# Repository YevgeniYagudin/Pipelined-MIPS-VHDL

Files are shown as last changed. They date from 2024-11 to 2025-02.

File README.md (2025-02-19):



Pipelined MIPS Processor
This project implements a pipelined MIPS processor written in VHDL, designed for integration on an Altera FPGA. The architecture efficiently executes instructions with support for stalls and flushes to handle hazards and maintain correct program behavior.
The design follows a five-stage pipeline, with each stage handled by a distinct sub-entity:

1. Ifetch (Instruction Fetch):
Reads program instructions and data from memory.
Passes the instruction to the next pipeline stage.

2. Idecode (Instruction Decode):
Decodes the instruction fetched by Ifetch.
Reads/writes data to/from registers as required by the instruction.

3. Execute:
Performs mathematical or logical operations on data from Idecode registers.
Outputs results for memory access or writes back to registers.

4. Dmemory (Data Memory):
Handles load and store operations.
Manages memory access as specified by the instruction.

5. Write Back:
Stores the result of execute stage in memory.

Control:
Enables or disables control signals for all components based on the current instruction.
Ensures correct operation and hazard handling.

Features
Pipelined Execution: Five-stage pipeline ensures efficient instruction throughput.
Hazard Handling: Supports stalls and flushes for resolving data and control hazards.
Supported Instructions: Implements the instructions specified by assignment requirements.
FPGA Integration: Designed for synthesis and deployment on FPGA hardware.
Deliverables
RTL Code: Fully implemented in VHDL.
Documentation: Includes design overview, block diagrams, and operational details.
Tested and verified on Quartus, ModelSim and QuestaSim. Integrated on Altera FPGA.

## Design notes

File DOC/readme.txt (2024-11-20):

The design includes a pipelined MIPS architecture.

Supported instructions are according to the assignment requirements.

The architecture supports stalls and flushes.

The top entity includes 5 main sub entities:

1.	Ifetch: Reads the program data, the instruction, and passes it to the next element.

2.	Idecode: Gets the instruction from Ifetch and reads/writes to registers.

3.	Control: Gets the instruction from Ifetch and enables/disables control signals to all relevant components.

4.	Execute: Gets the instruction from Idecode and applies mathematical operations on data given by Idecode registers.

5.	Dmemory: Loads and stores data according to instruction.

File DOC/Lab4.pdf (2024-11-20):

# CPU Architecture

# LAB 4 assignment

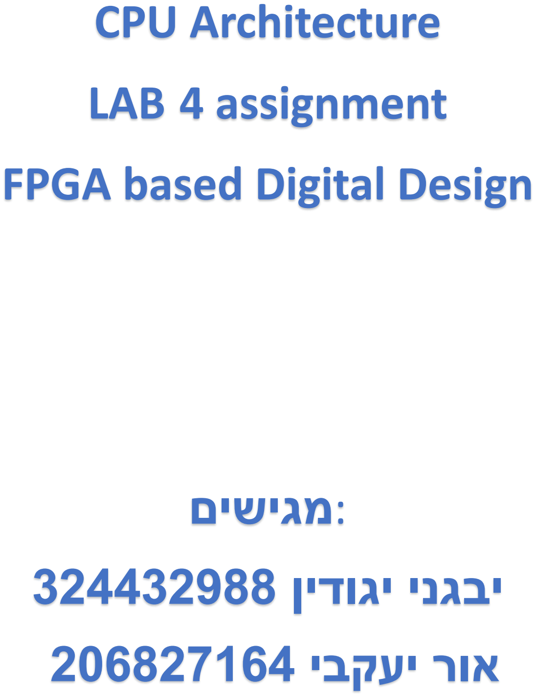
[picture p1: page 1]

# FPGA based Digital Design

# :מגישים

# יבגני יגודין 324432988

# אור יעקבי 206827164

חישוב התדר המקסימלי:

נעטוף ברגיסטרים את ה-ALU שלנו )TOP )כפי שהתבקש באיור הבא:

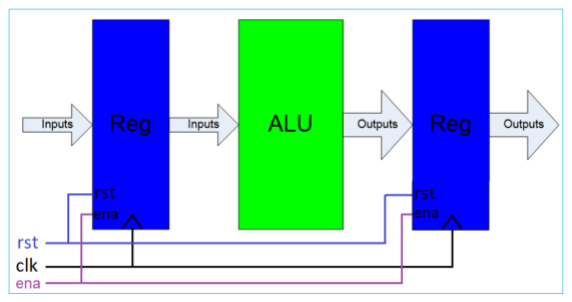
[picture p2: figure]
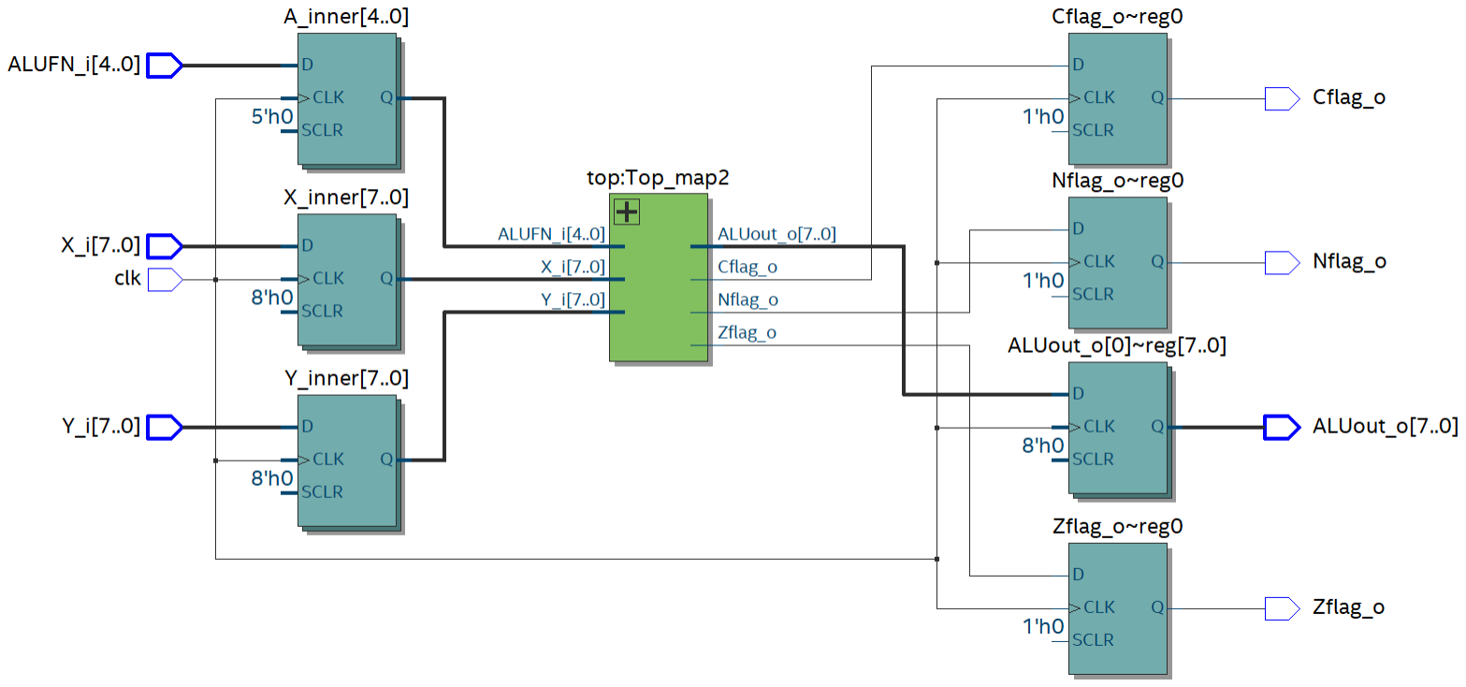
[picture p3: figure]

איור 1א: ה RTL של המערכת שלנו בצורה הזאת.

איור 1ב: נריץ את QUEST TIME וקיבלנו Mhz.108.53

תדר מקסימלי מקביל את המערכת שלנו בכך שאם יהיה יותר מידי גבוה, התוצאה של החישוב הסופי לא תספיק להתייצב בגלל מוגבלויות פיזיקליות ומכאן המערכת לא תיתן תשובה/תוצאה נכונה. לכל רכיב יש מדדים כמו זמן השהייה וכו'. ככלל לוקחים את מסלול צוואר בקבוק )קריטי( ולפי המוגבלויות שלו קובעים את התדר המקסימלי.

frequency limiting operation & | קריטי | מסלול

הבדיקה מראה שהמסלול הקריטי עובר דרך המחבר-מחסר .עובדה זאת לא מפתיעv כי הרכיב הזה מומש באופן תורי עם ה-FA שיש לו בפנים, ה-cout צריך עובר באופן גלי - תורי דרך כל ה-FA ומכאן ההאטה. לאומת זאת שיפטר ולוגיקה מומשו על ידי MUX-ים ובאופן מקבלי )או בקירוב מקבילי אם להזניח FANIN). זאת הסיבה שהמסלול קריטי של מחבר הוא כלול במסלול קריטי של כל המערכת. מסלול קריטי של יחידה לוגית ושפטר, ניתן לראות בהמשך בRTL שלהם, שבגלל שמומשו באופן מקבלי וMUX-ים כל המסלולים הפנימיים זהים כמעט. לכן המסלול הקריטי של מחבר הוא הכי מעניין.

איור :2 המסלול הקריטי של המערכת.

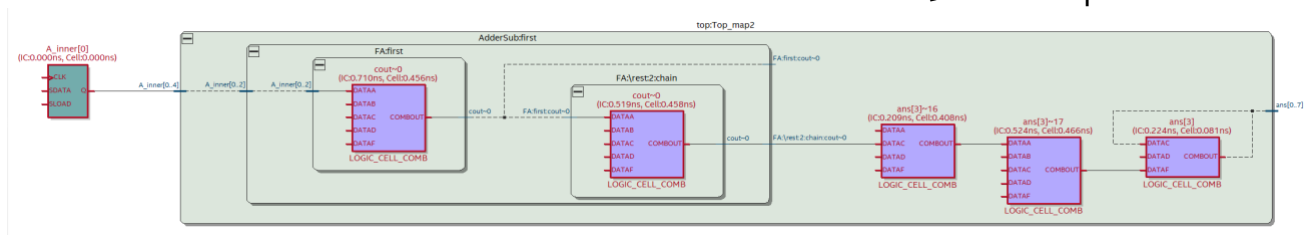
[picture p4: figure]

Logic resource usage summary

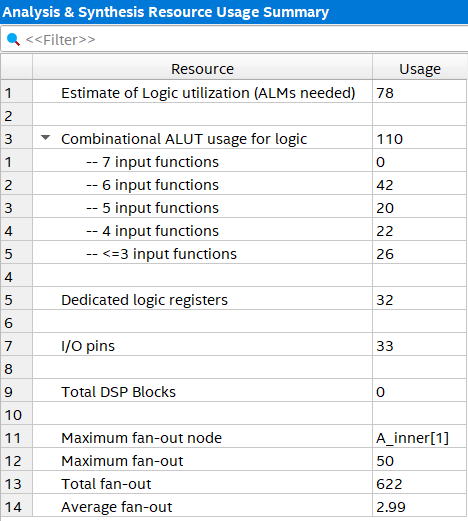
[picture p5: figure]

אופטימיזציות שנעשו בשביל ה-FPGA

כפי שהוגדר במטלה, נדרש "לצרוב" את ה-ALU על ערכת FPGA, איך ישנו צורך בהתאמות. התאמה ראשונה שנעשה היא בעקבות כך המערכת שלנו בעלת 3 כניסות, אבל סט הקלט שנבחר הוא מתגים והסט הזה הוא יחיד.
1( הוחלט ליצור ממשק קלט משוטף ל-X,Y,ALUFN אבל בתוספת סט KEY(ENA)+REGISTER כך שכל פעם כשנכניס קלט למערכת, נוכל להגדיר שמה שהקלדנו הוא למשל X ואז בפעם הבאה שנרצה להקליד Y, שוב נקליד את הערך ונלחץ על KEY שמשויך לרגיסטר של Y ולבסוף באותו אופן נכניס את הקוד של פעולה רצויה. )אין חשיבות לסדר הכנסת קלטים אפשר להתחיל מכל קלט, עקב הסימטריה והרגיסטרים ששומרים עת הערכים(

2( נדרש להציג על הלדים וגם על מסך HEX את שלושת הקלטים שנכנסו ל-ALU. X,Y נציג על מסך HEX בייצוג הקסדצימלי ואת ערך ALU נציג בייצוג בינארי על הלדים. ייצוג הלדים הוא ישיר, פשוט הוצאנו את האות החוצה כפלט נוסף שממופה ללדים. את הייצוג של X,Y נדרש להציג על גבי זוג מסכים 7 סגמנטים כל אחד. לכן יצרנו ישות חדשה שממירה 4 ביטים ל7- ביטים לפי טבלת אמת שיצרנו תוך הסתכלות על מספרי סגמנטים בחוברת. לאחר מכן הרחבנו את הישות שתמיר מ8- ל14- ביטים שיתאים למספר הביטים של X, Y.

3( באותו אופן כמו בסעיף הקדום עשינו עבור פלט המערכת. התוצאה תוצג בייצוג HEX על גבי מסך HEX אחרי ההמרה והדגים יוצגו כביט בודד כל אחד על גבי לדים.

לסיכום: ערכי X, Y והתוצאה יוצגו על 6 מסכי HEX, כל אחד מקבל 2 מסכי HEX. ערכי ALU והדגלים יוצגו על גבי לדים. הקלט יתקבל ממתגים כך שכל פעם נוכל להגיד מה הוקלד ולסמן איזה מה מבין X,Y, ALUFN הוקלד

בעמוד זה וב2- עמודים הבאים נציג את ה RTL של הרכיבים.

איור :3 המעטפת שיצרנו סביב ה-ALU כדי להתממשק לערכה והתאמה ל-IO שלה.

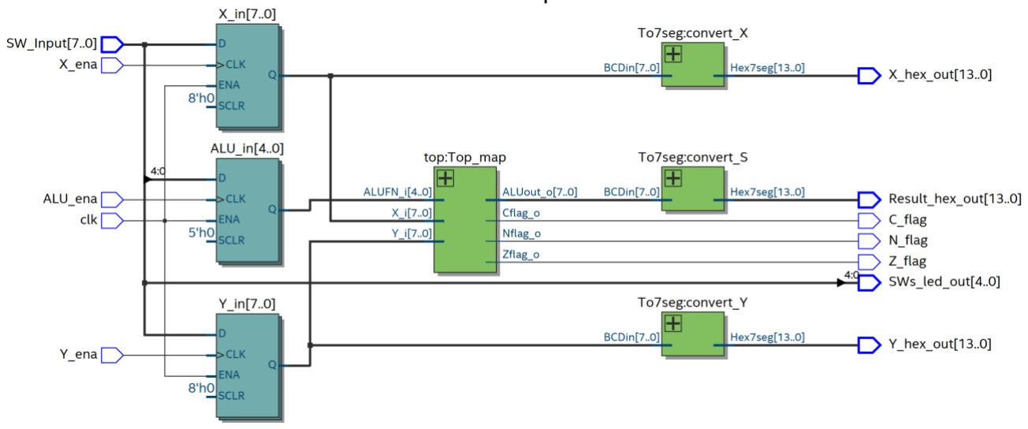
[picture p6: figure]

הערה: המערכת א-סינכרונית ולכן אין באמת CLK האיור נעשה לפני שתיקנו את זה.

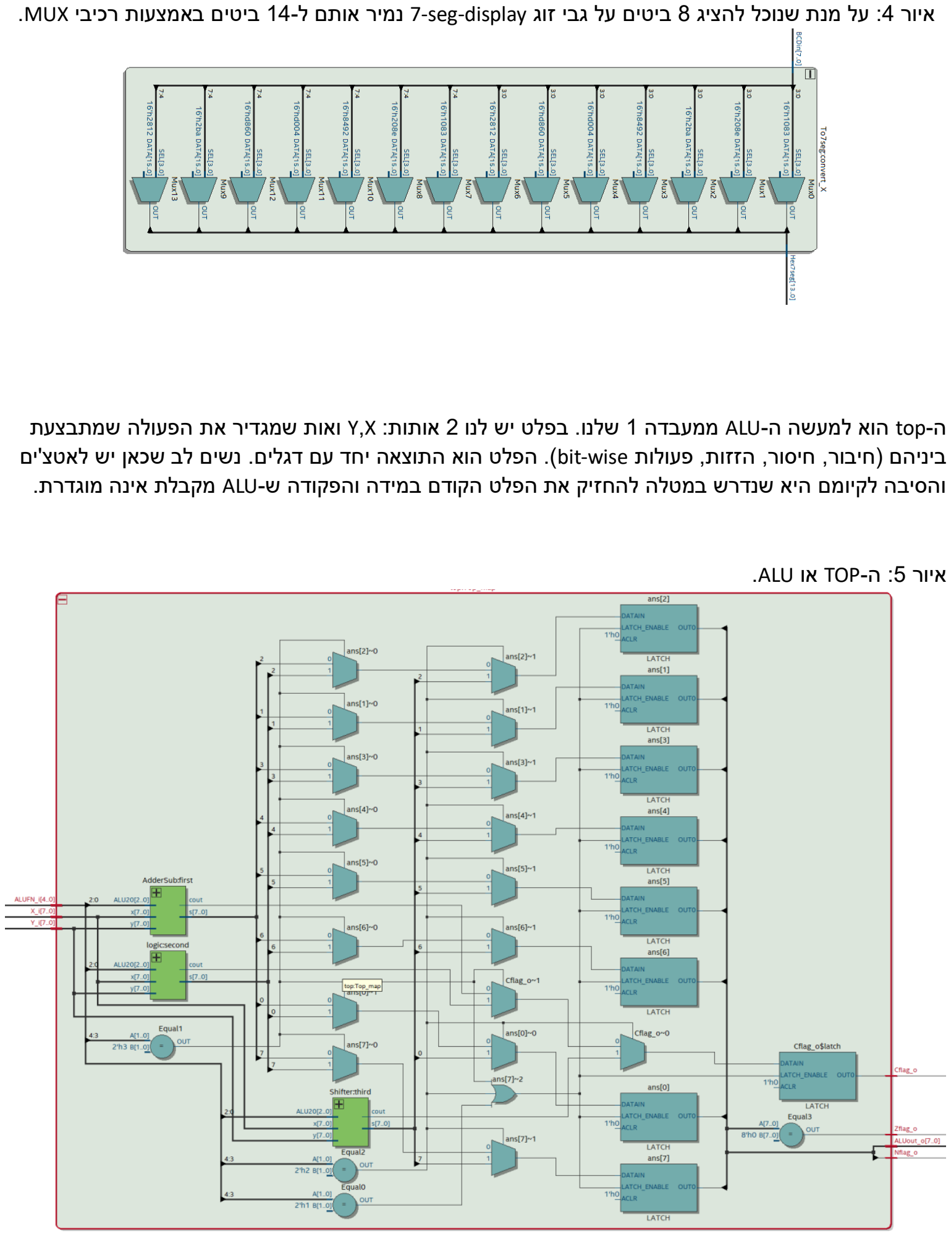
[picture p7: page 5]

איור :4 על מנת שנוכל להציג 8 ביטים על גבי זוג display-seg7- נמיר אותם ל14- ביטים באמצעות רכיבי MUX.

ה-top הוא למעשה ה-ALU ממעבדה 1 שלנו. בפלט יש לנו 2 אותות: X,Y ואות שמגדיר את הפעולה שמתבצעת ביניהם )חיבור, חיסור, הזזות, פעולות wise-bit). הפלט הוא התוצאה יחד עם דגלים. נשים לב שכאן יש לאטצ'ים והסיבה לקיומם היא שנדרש במטלה להחזיק את הפלט הקודם במידה והפקודה ש-ALU מקבלת אינה מוגדרת.

איור :5 ה-TOP או ALU.

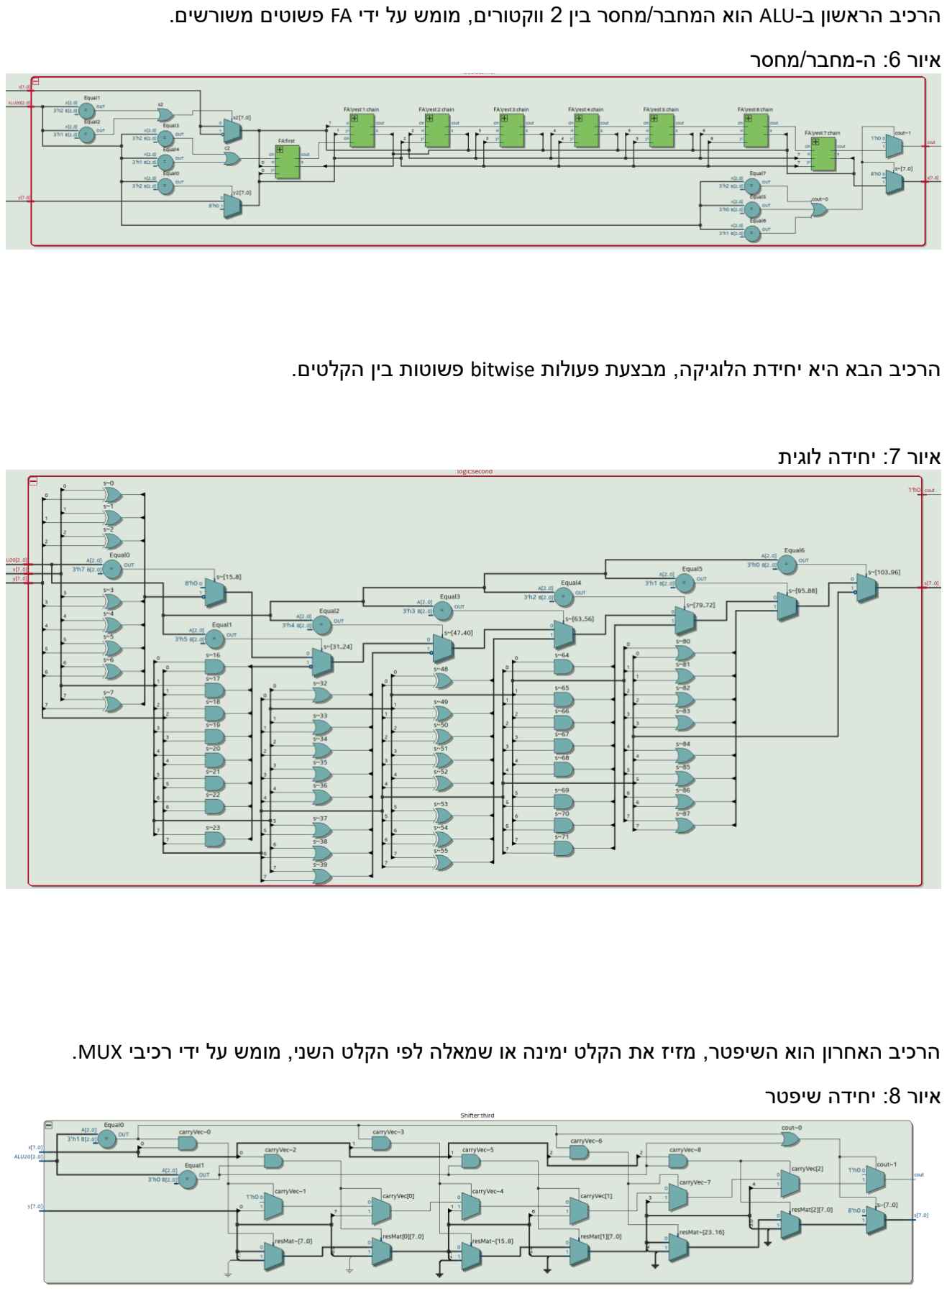
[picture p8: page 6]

הרכיב הראשון ב-ALU הוא המחבר/מחסר בין 2 ווקטורים, מומש על ידי FA פשוטים משורשים.

איור :6 ה-מחבר/מחסר

הרכיב הבא היא יחידת הלוגיקה, מבצעת פעולות bitwise פשוטות בין הקלטים.

איור :7 יחידה לוגית

הרכיב האחרון הוא השיפטר, מזיז את הקלט ימינה או שמאלה לפי הקלט השני, מומש על ידי רכיבי MUX.

איור :8 יחידה שיפטר

The testbench

נבצע את הבדיקה על TB של MODELSIM על המערכת הכי גבוהה, זאת אומרת המערכת שכבר מותאמת לFPGA שלנו, נשים לב שעדיין מדובר ב-ALU שכבר דיברנו עליו וביצענו עליו הרבה בדיקות ולכן המטרה המרכזית של הTB הזה היא לבדוק את הלוגיקה הנוספת שהוספנו, מסכי HEX, לדים, מתגים.

איור :9 הצגת תוצאת הסימולציה

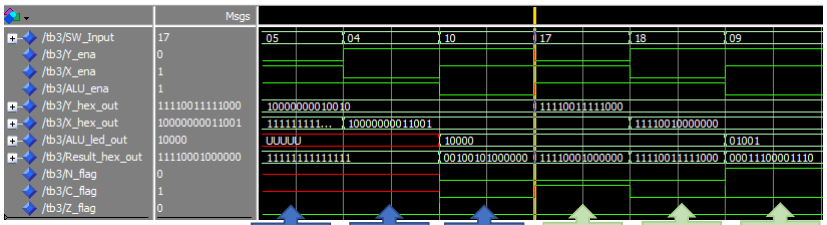
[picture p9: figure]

הקו מציג עם "HEX "בשם מוצגים אחרי המרה למסך HEX. נריץ בדיקות:

בדיקה :1 SHIFTER

Y = 1000000 ⏟

0

0010010 ⏟

5

= 05ℎ ; X = 1000000 ⏟

0

0011001 ⏟

4

= 04ℎ ; Result = 0010010 ⏟

5

1000000 ⏟

0

= 50ℎ = 80

→ so tℎe calculation is ∶ 5 ∗ 2

4 = 80 → correct

בדיקה :2 ADDER

Y = 1111001 ⏟

1

1111000 ⏟

7

= 17ℎ ; X = 1111001 ⏟

1

0000000 ⏟

8

; Result = 0001110 ⏟

F

0001110 ⏟

F

= FFℎ =⏟

2′s

− 1

→ so tℎe calculation is ∶ 17ℎ − 18ℎ = FFℎ =⏟

2

′s

− 1 → correct + Nflag

הערה :1 סוגריים מסולסלות אופקיות מסמנות המרה למסך HEX ולא ייצוג HEX. זה נעשה על ידי ישות converter שממירה באופן שמוצג משמאל )קטע קוד(. הערה :2 אותות מסוג EN ואות התוצאה מוצגים כ-not מהסיבה שככה מוגדרת הערכה, וכפתורי KEY שקשורים ל-EN הם מקבלים 0 לוגי בלחיצה, בדומה גם הפלט למסכי HEX.

Y<-5 | X<-4 | Shl 5,4 | Y<-17 | X<-18 | Y-X=9

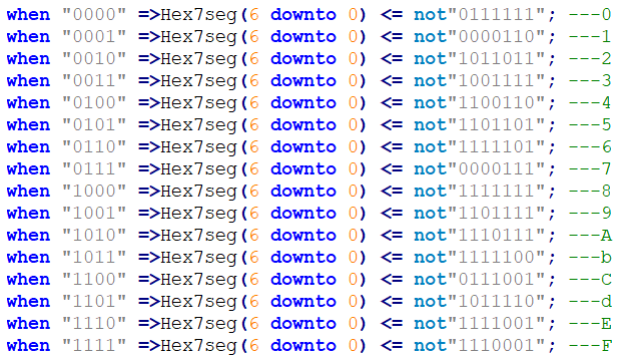
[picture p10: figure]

### signal tap בדיקת

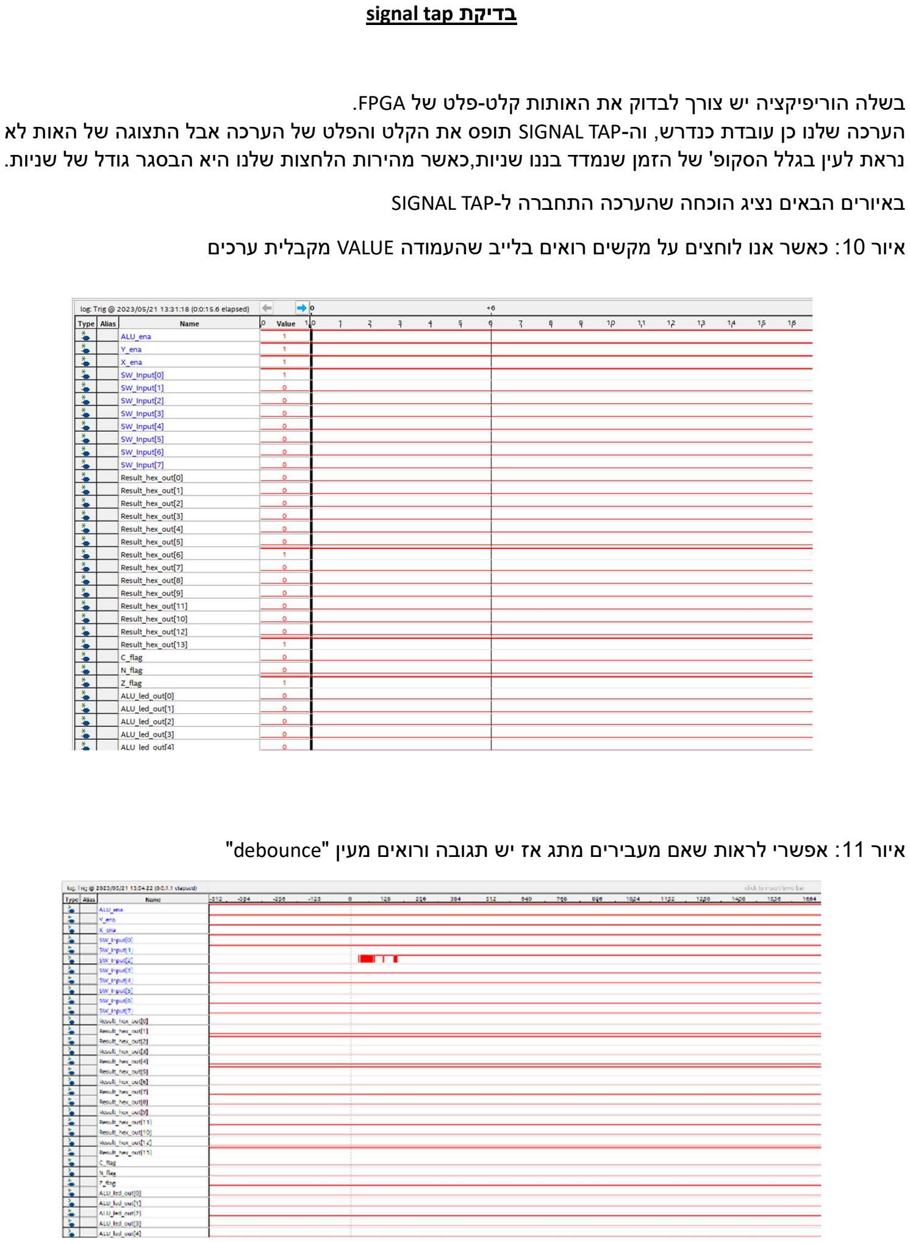
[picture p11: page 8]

בשלה הוריפיקציה יש צורך לבדוק את האותות קלט-פלט של FPGA. הערכה שלנו כן עובדת כנדרש, וה-TAP SIGNAL תופס את הקלט והפלט של הערכה אבל התצוגה של האות לא נראת לעין בגלל הסקופ' של הזמן שנמדד בננו שניות,כאשר מהירות הלחצות שלנו היא הבסגר גודל של שניות.

### באיורים הבאים נציג הוכחה שהערכה התחברה ל-TAP SIGNAL

### איור :10 כאשר אנו לוחצים על מקשים רואים בלייב שהעמודה VALUE מקבלית ערכים

### איור :11 אפשרי לראות שאם מעבירים מתג אז יש תגובה ורואים מעין "debounce "

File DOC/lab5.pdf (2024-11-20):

# CPU Architecture

# LAB 5 assignment

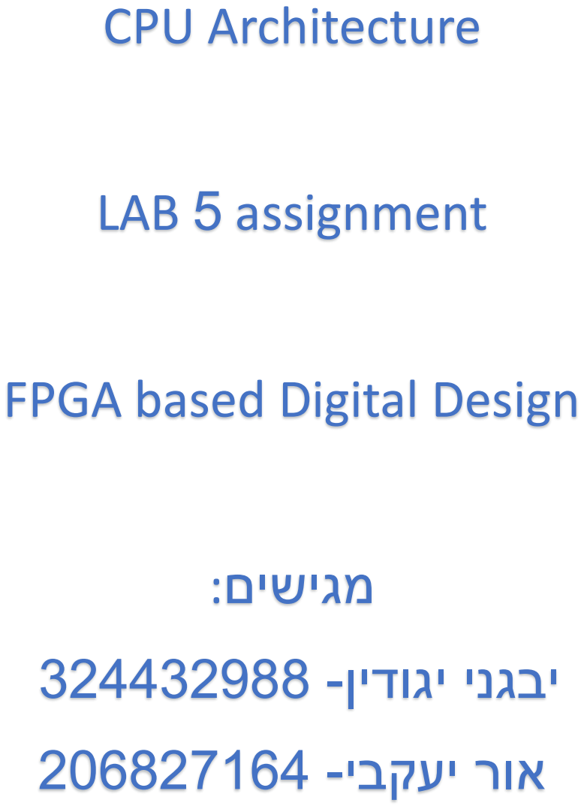
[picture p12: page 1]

# FPGA based Digital Design

# מגישים:

# יבגני יגודין- 324432988

# אור יעקבי- 206827164

:TOP LEVEL BLOCK

הצלחנו לממש את כל הפקודות , שידרגנו את המערכת ל- PIPELINED , מימשנו FLUSH וגם HAZARD DETECTION ובפרט- STALL .( לא הצלחנו לממש את FORWARDING לצעריינו(

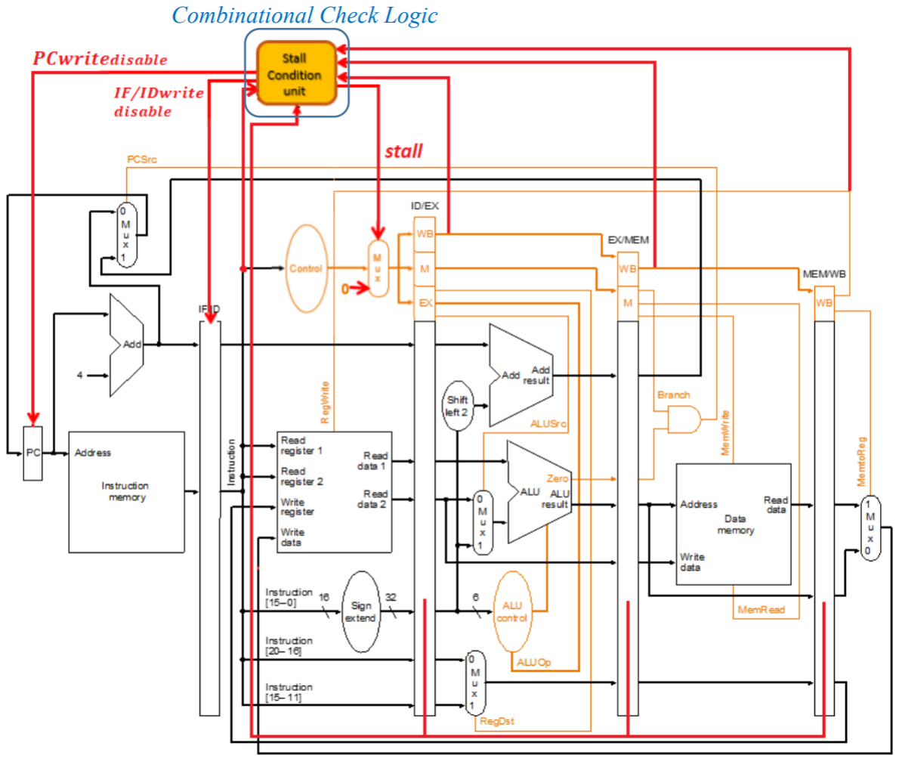
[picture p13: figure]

ה-TOP שלנו בנוי ממש כמו בשרטוט הבא עם הפלטים והקלטים הבאים:

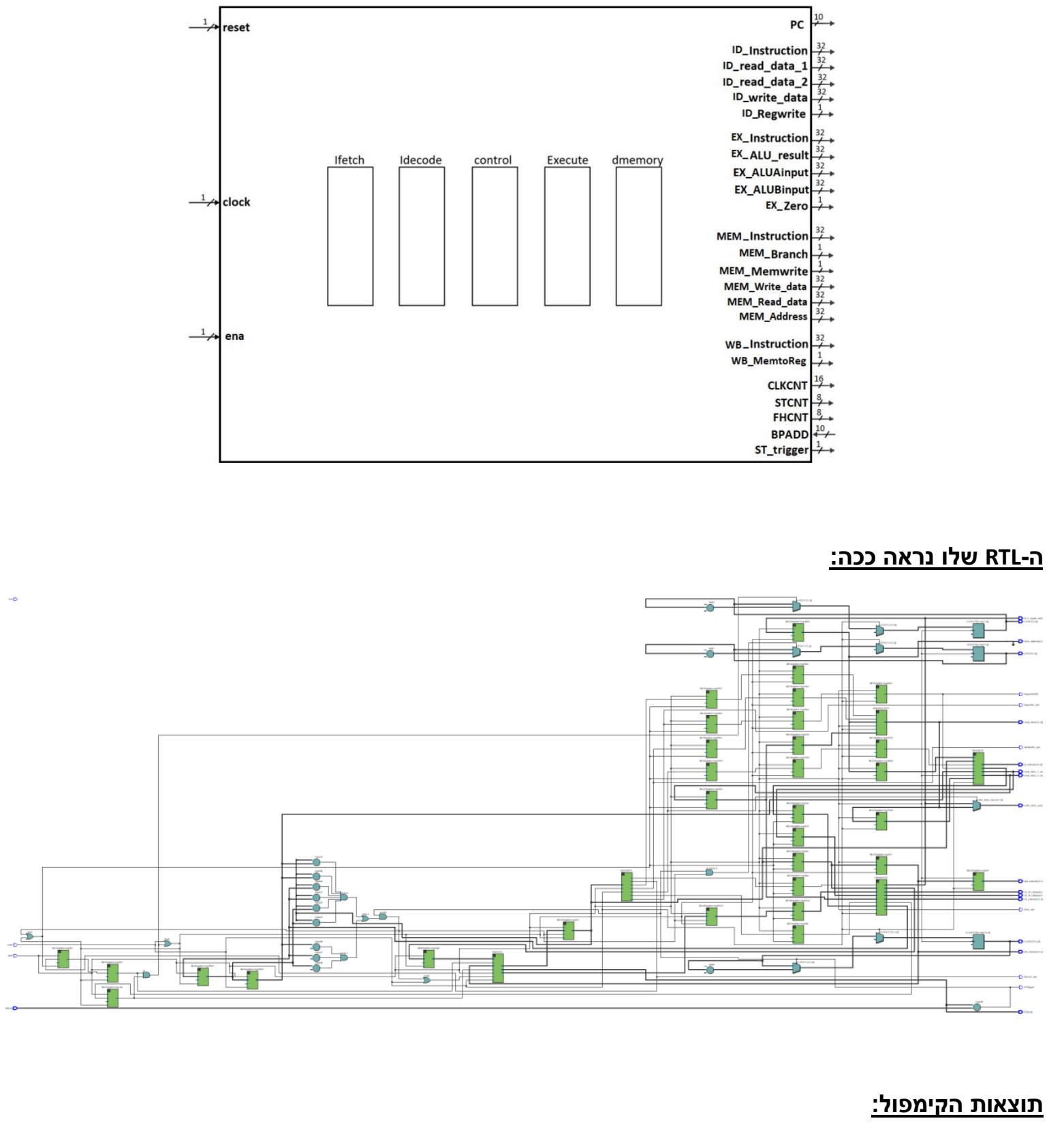
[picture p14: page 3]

ה-RTL שלו נראה ככה:

תוצאות הקימפול:

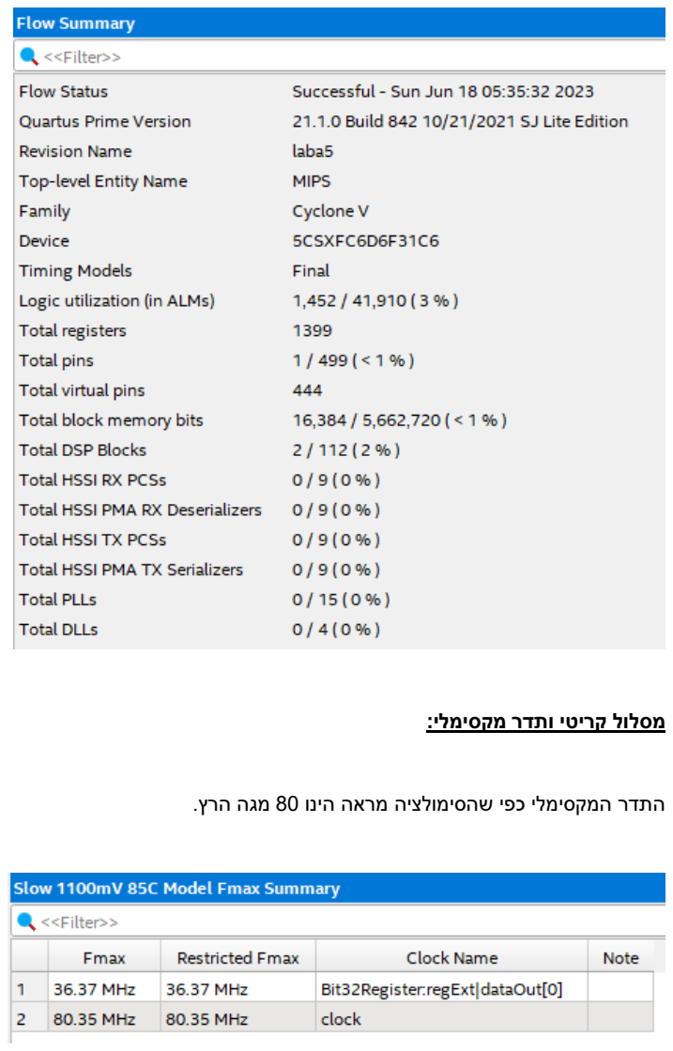
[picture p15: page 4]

מסלול קריטי ותדר מקסימלי:

התדר המקסימלי כפי שהסימולציה מראה הינו 80 מגה הרץ.

המסלול הקריטי עובר דרך יחידת execute ובפרט דרך המכפל. זה לא מפתיה שהמסלול עובר דרך מכפל כי המכפל הוא יחידה ממש כבדה בסיבוכיות ריצה בגלל המימוש הטורי שלה.

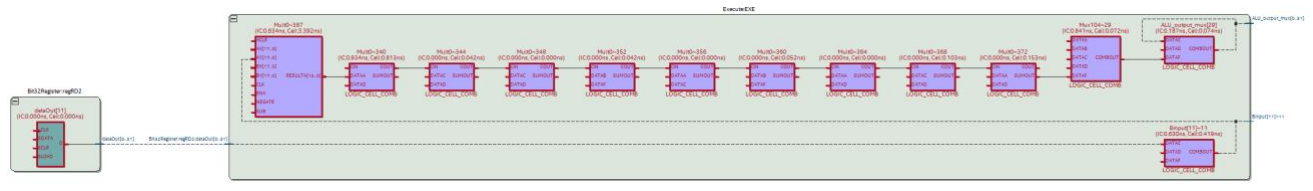
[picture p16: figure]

נדבר על כל תת בלוק בנפרד:

FETCH

הרכיב מקדם את ה-PC וקורא מן קובץ מקור את רשימת פקודות או קוד שעליו לבצע.

את הפקודה שקרא, מעבר לשאר המערכת בצורה טורית.

כמו כן יש בו מנגנון של הסתעפויות.

ה-RTL

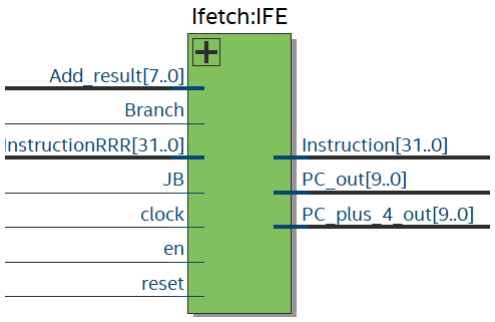
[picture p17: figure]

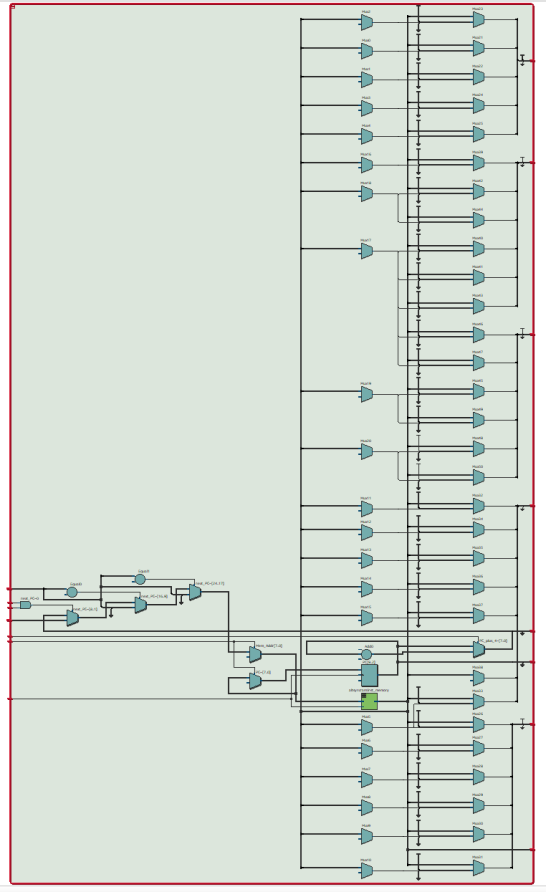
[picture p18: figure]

CONTROL

היחידה מקבלת את הפקודה ובהתאמה מפעילה קווי בקרה מתאימים בכל שכבה בנפרד.

למשל פותחת אופציה לקרוא או לכתוב מזכרון או מרגיסטרים.

ה-RTL

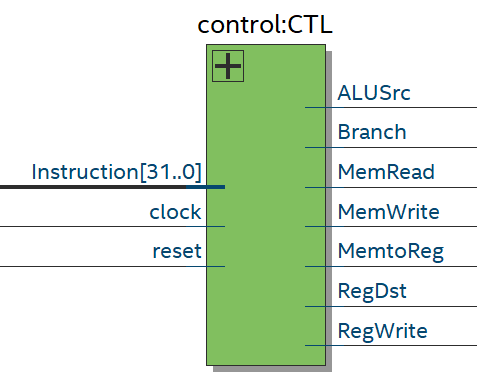
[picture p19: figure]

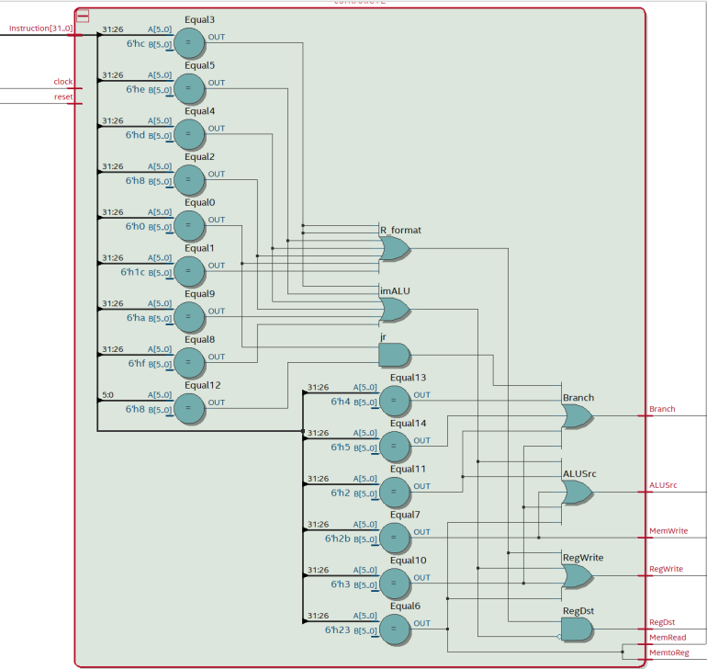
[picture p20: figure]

DECODER

היחידה מקבלת את הפקודה מ-IFETCH ובהתאמה מפרשת אילו רגיסטרים הם מקור, מטרה ויעד ובהתאמה פותחת אותם לקריאה ולכתיבה אם מדובר ברגיסטר יעד. כל זה תוך כדי הקשבה לקווי בקרה של CONTROL ועוד.

ה-RTL:

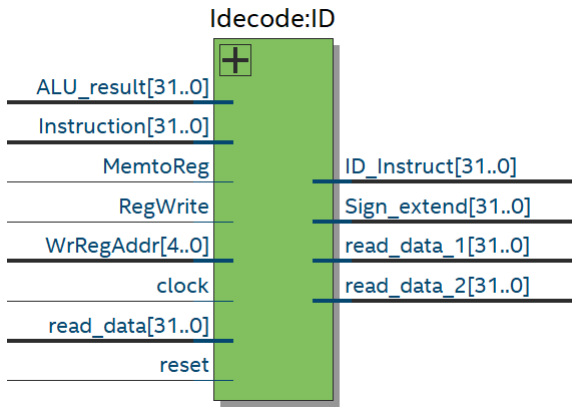
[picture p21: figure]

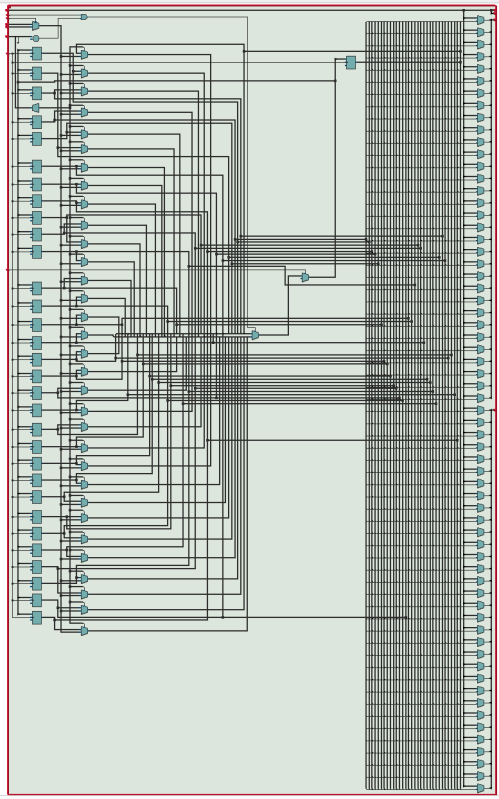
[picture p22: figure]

EXECUTE

היחידה מבצעת פעולות מתמטיות לפי הפקודה שקיבלה ו-DECODER. ה-DECODER מספק אותה בתוכן הרגיסטרים שעליהם יבוצעו הפעולות. היחידה גם מחשבים האם יקרו חלק מההסתעפויות )למשל BNE/BEQ )

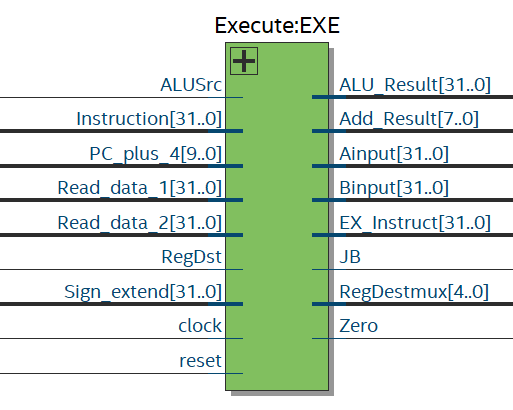
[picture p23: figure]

ה-RTL

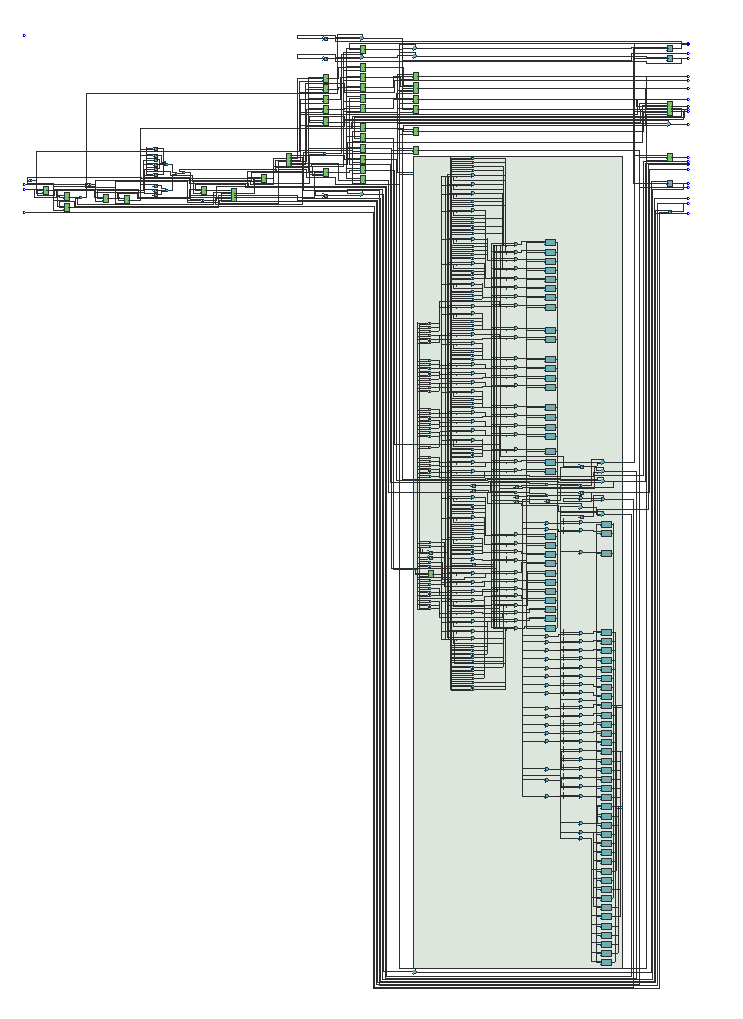
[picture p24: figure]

DATA MEMORY

היחידה טוענת את הזכרון ההתחלתי ועובדת איתו במהלך הקוד. ניתן לקרוא ממנה וגם לכתוב אליה במהלך הריצה או בסוף הריצה לפי הצורך. השליטה בכתיבה/קריאה/כתובת מתבצעת דרך CONTROL ו-תוצאת EXECUTE.


ה-RTL


SINGAL TAP

לאחר צריבה של קודה ל-FPGA הרצנו את ה-TAP SIGNAL.

בריצה רגילה נראה את הקווים עובדים, למעלה השעון רץ ו- CLKCNT עובד כ-COUNTER כצפוי.

בתמונה הבאה רואים את אותו דבר אבל זמן שמתג SW9- סגור. כלומר ה-ENA מכובה ולכן הקווים שתקו, חוץ מהשעון שהוא כמובן פועם

בתמונה הבאה רואים את המשך של תמונה ראשונה, פשוט קווים אחרים.

בתמונה הבאה רואים את המערכת כש0-KEY לחוץ כלומר יש RESET קבוע.


קוד מטריצות:

השוואת תוכן הזיכרון נתונים :

ניתן לראות שתוכן מטריצת התוצאה זהה.


השוואת תוכן הרגיסטרים

Wave form:

גם כאן ניתן לראות את הצורה האלכסונית של דחיפת הפקודות ב פייפליין, ספירת הסטולים והפלאש.

בסוף התכנית:

IPC =

CLKCNT − (STCNT + 4 + FHCNT ∗ dept)
CLKCNT | =

491 − (26 + 4 + 10 ∗ 3)
491 | = 0.87

נשים לב שכמות הסטולים נמוכה מכיוון שאין לנו בקוד פקודות קריאה- כתיבה ואין סטולים כי אין הרבה קפיצות לכן קיבלנו תוצאה יחסית גבוה.

דוגמה לקוד שלנו – QA( הקבצים של DO )שייכים לקוד הזה.

נדגים את הקוד שלנו שכתבנו, הוא מכיל את כל הסוגים של הסתעפויות ותלויות בין רגיסטרים. ונציג את תוכן הרגיסטרים בסיום הריצה לפי MARS ולפי סימולציית MODELSIM.

בצד ימין, תוכן הרגיסטרים לפי MARS ,באמצע לפי MODELSIM ובצד שמאל הקוד עצמו.


נשים לב שהתוכן זהה מלבד רגיסטרים 28/29 ש-MARS משתמש למטרות אחרות ומלבד רגיסטר 31 ששמר את הכתובה חזרה לאחר פקודת JAL. כלומר התוצאה נכונה.

נביט בזיכרון בשתי המצבים, נראה שהוא גם זהה.

WAVE FORM

נביט בגדלים של הריצה.


רואים שכל פעם שיש לנו קפיצה ב-BRANCH אז המונה FHCNT גדל ב1- כמצופה. רואים מהקוד, שכמעט כל פקודה מבצעת כתיבה לרגיסטרים ורואים זאת מהגלים, האות REGWRITE דולק כמעט תמיד.

אם להביט רק באותות שונים של INSTRUCTION ניתן לראות את הצורה האלכסונית של ביצוע הפקודה לפי כל רכיב. כמו כן גם סטולים/FLUSH שמתקיימים במהלך.

הערה: בקוד המקורה היו לנו את כל ה5- שלבים אבל בקוד שמגישים התבקש רק 3 שלבים

נביט ברגיסטרים שהוספנו כדי לחשב את ICP:

CLKCNT = 96

STCNT = 51

FHCNT = 5

IPC =

CLKCNT − (STCNT + 4 + FHCNT ∗ dept)
CLKCNT | =

96 − (51 + 4 + 5 ∗ 3)
96 | =

13
48 ≈ 0.271

התוצאה דיי נמוכה, זאת משום שהקוד נכתב בכוונה עם הרבה תלות בין פקודות על מנת לסבך וליצור הרבה סטולים ולעשות קפיצות בתהליך.

דוגמה לקוד שלנו – QA diviation


הקוד מבצע את החישוב 16/2=8 ללא פעולת div כמובן. הכנסנו עוד כמה פעולות מיותרים על מנת ליצור סטולים מכוונים.

תוכן הרגיסטרים והזיכרון נתונים זהה.

WAVE FORM

נביט בגדלים של הריצה.


IPC =

CLKCNT − (STCNT + 4 + FHCNT ∗ dept)
CLKCNT | =

203 − (111 + 4 + 10 ∗ 3)
203 | = 0.28

קיבלנו מספר קטן יחסית כי בכל לולאה ישנם 2 פקודות קפיצה היוצרות סטול ופלאש ובנוסף הכנסנו פקודת קריאה-כתיבה היוצרות סטול נוסף

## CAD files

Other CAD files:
Quartus/stp1.stp

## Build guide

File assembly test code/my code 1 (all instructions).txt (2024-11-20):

	addi $1 $1 222
	add $2 $1 $1
	sub $3 $2 $1
	sll $4 $3 17
	srl $5 $4 3
	srl $6 $4 3
	lui $7 111
	move $8 $5
	move $9 $7
	xor $10 $7 $6
	xori $11 $10 747
	beq $5 $6 L
L2:	sll $4 $4 11
	slt $13 $10 $11
	slti $14 $10 999
	slti $15 $10 999
	sw $1 0($0)
	sw $2 4($0)
	sw $3 8($0)
	sw $4 12($0)
	jal L3
	j fin
L:	sw $5 16($0)
	j L2
L3:	add $1 $2 $3
	addi $1 $ra 0
	jr $1
	
fin:	add $1 $2 $2
	add $2 $3 $4
	add $3 $5 $6
	add $4 $7 $8
	add $5 $1 $2
	add $6 $3 $4
	add $7 $5 $6

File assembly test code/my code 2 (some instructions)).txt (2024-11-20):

    .data
result: .word 0        # Memory location to store the result

    .text

    addi $t0,$0, 16          # Load dividend value into $t0
    addi $t1,$0, 2           # Load divisor value into $t1
    addi $ra , $0,100

    # Initialize variables
    move $t2, $zero     # Quotient: $t2 = 0
    move $t3, $t0       # Remainder: $t3 = $t0
    addi $t7, $0,1

loop:
    bne $t3, $t1, subtract   # Branch to subtract if remainder != divisor
    addi $zero,$zero,0
    addi $t2, $t2, 1        # Increment quotient
    j end                   # Jump to end

subtract:
    sub $t3, $t3, $t1       # Subtract divisor from remainder
    addi $t2, $t2, 1        # Increment quotient
    sub $t2 , $t2,$t7      #stall check
    addi $t2,$t2,1
    j loop                  # Jump to loop

end:  
    addi $zero,$zero,0
    add $t3, $t3, $t1       # Add divisor to remainder

    sw $t2, result          # Store the result in memory location 'result'
    jr $ra                      # Return
